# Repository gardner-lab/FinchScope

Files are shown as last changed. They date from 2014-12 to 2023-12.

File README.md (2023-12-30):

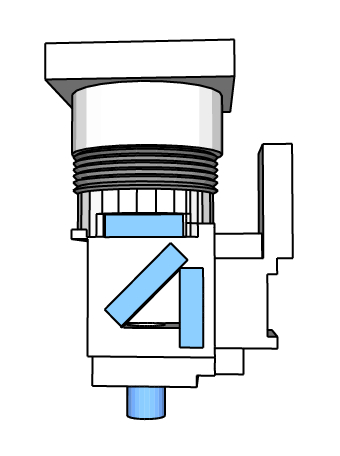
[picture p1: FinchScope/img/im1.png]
<font size="10"> FreedomScope Project</font>
=======

============

## Overview

FreedomScope is an umbrella project for several customizable and scaleable single-photon fluorescent imaging microscope systems that take advantage of developing open-source landscape to provide a modular in-vivo  all optical neurophysiology rigs with a transparent hardware, and  acquisition and analysis software.

You can read more about the project [here.](http://iopscience.iop.org/1741-2552/14/4/045001/)

The project was developed by [Will Liberti](https://github.com/WALIII) in the [Gardner Lab](http://people.bu.edu/timothyg/Home.html), for multi-month imaging of neural activity in songbirds [[1]](https://doi.org/10.1371/journal.pbio.1002158) [[2]](https://www.nature.com/articles/nn.4405) [[3]](https://ccneuro.org/2018/proceedings/1133.pdf) bats, and rodents. This effort would not have been possible without the critical advice and support at the outset of the project by Daniel Aharoni and Peyman Golshani, of the [UCLA Miniscope project](http://miniscope.org/index.php?title=Main_Page)

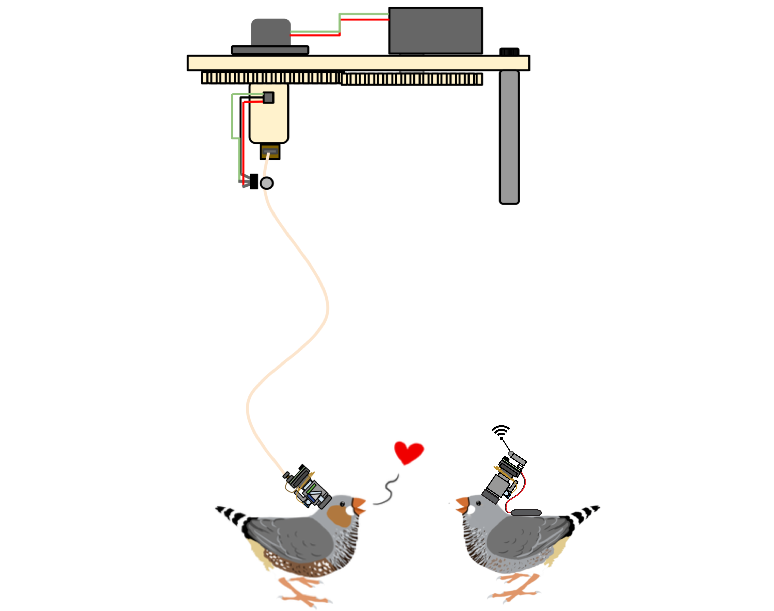
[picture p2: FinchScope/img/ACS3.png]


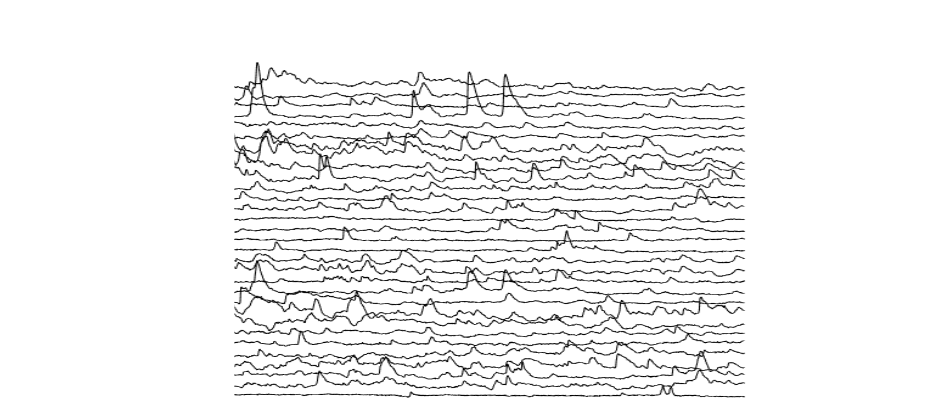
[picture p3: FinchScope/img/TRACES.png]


#### Components:

### Finchscope Microscope

The FinchScope is a lightweight wireless-capable microscope for biological imaging- Designed specifically for monitoring the neural activity (via genetically encoded calcium indicators) of zebra finches while they sing their courtship songs:

<p align="center" width="100%">
    
</p>

You can find the Construction and Assembly Guide for [the Microscope](https://github.com/WALIII/FreedomScope/wiki/Assembly-Guide), As well as a for the [Data Acquisition Box (DAQ)](https://github.com/WALIII/FreedomScope/wiki/DAQ-Guide).  Also, we have a [Guide Through a Basic Analysis Pipeline](https://github.com/WALIII/FreedomScope/wiki/Analysis-Guide)

#### Wireless Finchscope
The FinchScope is wireless capable and is being used in bats with the Yartsev lab:

<p align="center" width="100%">
    
</p>

Additional resources related to this project can be found (here.)https://github.com/WALIII/ImBat

### 1P2C Microscope (Under Development)
The 1P2C Miniscope is a variant of the FinchScope that incorporates a second excitation path for dual color imaging, or for widefield photo- stimulation.  You can find the Construction and Assembly Guide for [the Microscope](https://github.com/WALIII/FreedomScope/wiki/Assembly-Guide), As well as a for the [Data Acquisition Box (DAQ)](https://github.com/WALIII/FreedomScope/wiki/DAQ-Guide).

### Widefield Microscope (Under Development)
The WideField miniature microscope weighs 4g and gives a 4x3mm field of view. You can find the Construction and Assembly Guide for [the Microscope](https://github.com/WALIII/FreedomScope/wiki/Assembly-Guide), As well as a for the [Data Acquisition Box (DAQ)](https://github.com/WALIII/FreedomScope/wiki/DAQ-Guide).

### Active Commutator
The [Active Commutator](https://github.com/WALIII/FreedomScope/wiki/Commutators) is a low cost, low noise, active (driven by a motor and sensor) electrical rotary joint designed for electrophysiology (single and multichannel micro-electrode arrays) and optophysiology ( optogenetics, miniature microscopes, and fiber photometry).

### Referencing
If you use any part of this project in your work, please cite our Journal of Neural Engineering Paper:

[Liberti III, William A., et al. "An open source, wireless capable miniature microscope system." Journal of neural engineering 14.4 (2017): 045001.](http://iopscience.iop.org/1741-2552/14/4/045001/)

### Publications that use the FinchScope:
* Liberti, W., et al.  **Nature Neuroscience** 19.12 (2016): 1665-1671.
* Liberti, W., et al.  **Journal of Neural Engineering** 14.4 (2017): 045001.
* Yanny, K., Antipa, N., Liberti, W., et al. (2020). **Light: Science & Applications**, 9(1), 1-13.
* Cohen, Y, et al.  **Nature** 582.7813 (2020): 539-544.
* Leman, D., et al.  **(BioRxiv)** (2021).
* Singh Alvarado, J., et al. **Nature** 599.7886 (2021): 635-639.
* Liberti, W., et al.  **Nature** 604.7904 (2022): 98-103.
* Forli, A., et al. **Nature** 621.7980 (2023): 796-803.

## Contributors:
* [Will Liberti](wliberti@berkeley.edu) (U.C. Berkeley, LBNL, Morphosis Neurotech)
* [Nathan Perkins](lnp@bu.edu) (Apple)
* [Daniel Leman](dpleman@bu.edu) (Brandeis)
* [Jasmine Clevenger](jrclev@bu.edu) (Bosotn U.)
* [Will Yen](yenw24@gmail.com) (Boston U.)

##  Major Contributing Labs
* [Gardner Lab](idavison@bu.edu)
* [Otchy Lab](idavison@bu.edu)
* [Davison Lab](idavison@bu.edu)  
* [Cruz-Martin Lab](idavison@bu.edu)  
* [Carmena Lab](idavison@bu.edu)  
* [Yartsev Lab](idavison@bu.edu)

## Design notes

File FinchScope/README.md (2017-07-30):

<font size="10">    FinchScope</font>
============
## Overview

The project is now in live. If you have questions or find bugs, feel free to [post an issue](https://github.com/WALIII/FinchScope/issues) and I'll get on it.

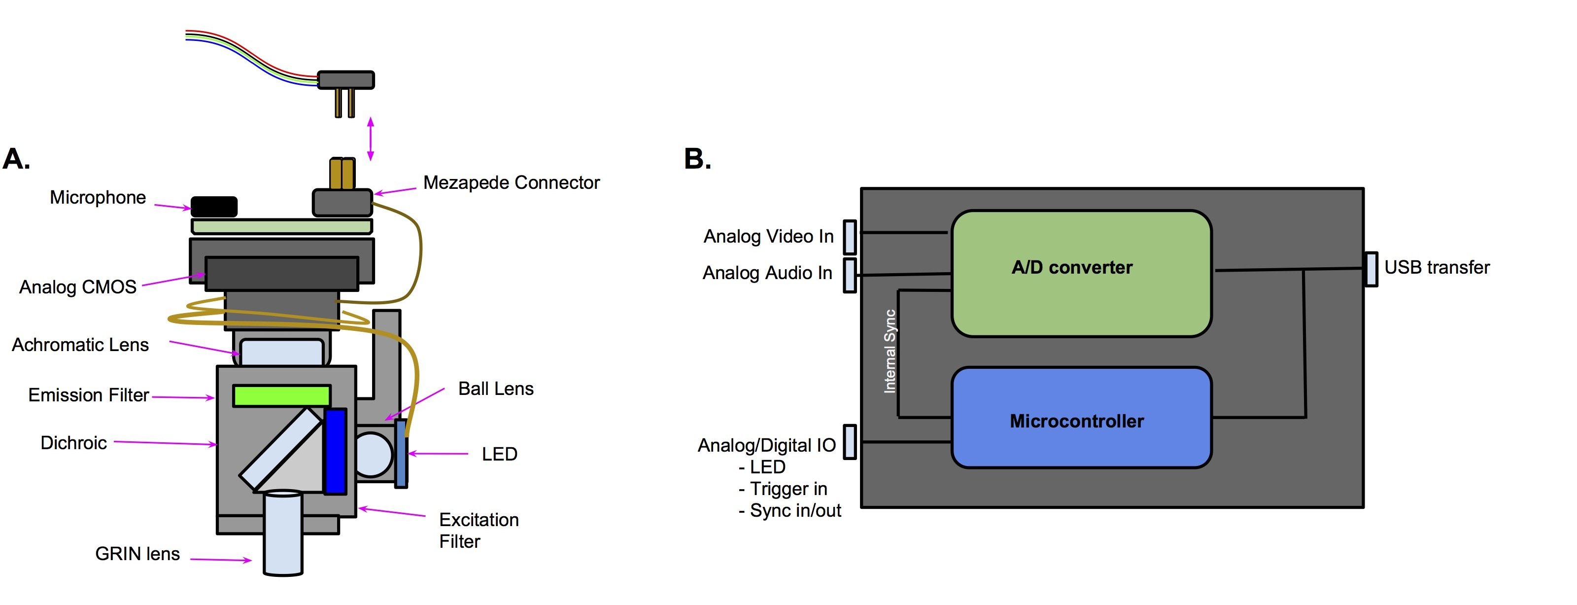
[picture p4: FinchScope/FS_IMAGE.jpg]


The FreedomScope is a lightweight (<2g) 3D printed microscope for biological imaging, specifically designed for fluorescence calcium imaging in Zebra Finches and other small animals.

#### Hardware Components:

[PARTS LIST](https://docs.google.com/a/bu.edu/spreadsheets/d/1X6249HvX6Zhh-KnQvc4uEf_1f7gnXYBuc04Sh4Ooo6Y/edit?usp=sharing)

##### Detailed Assembly Schematics:

[CAMERA](https://docs.google.com/drawings/d/1Mr2SnDT4y19bNpteDOJaQ2hIX_aQwCAYKedkWsTO91U/edit)

[TEST CABLES](https://docs.google.com/drawings/d/1CfU9u8T49LHIxU1WA31IjVRijmX2HUkyHNBYetaNZlw/edit)

[COMMUTATOR INTERFACE](https://docs.google.com/drawings/d/1axYK-PdhWuuLdrFH5zi7WUmzpqFvBdvdiIFzCNW9POA/edit)

### DAQ BOX
The DAQ converts/syncs audioIN and video, Triggers in/out, and also controls LED power levels

[DAQ Overview] (https://docs.google.com/drawings/d/1Maer1AkDQlLleWU_moi8kYX32AhPPOLMHTUVHxjg2Lc/edit)

[Internal Wiring Diagram](https://docs.google.com/drawings/d/1Maer1AkDQlLleWU_moi8kYX32AhPPOLMHTUVHxjg2Lc/edit)

I like to use [these Connectors](http://www.advanced.com/products/board-to-board-connectors/mezza-pede-smt-connectors/table-of-models)

## SOFTWARE

#####NEW Software (MAC 10.7 or later):
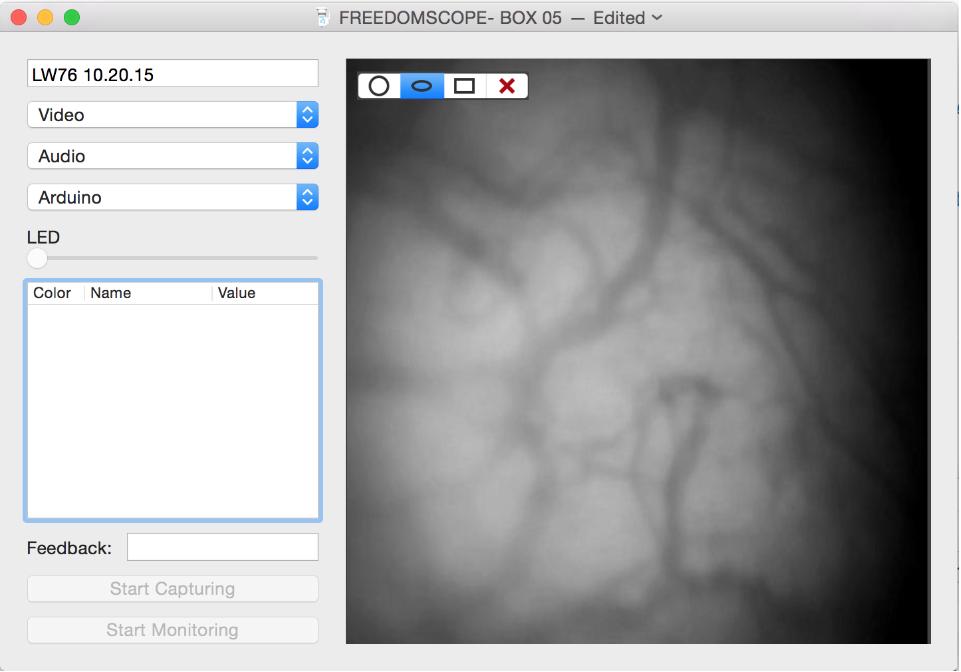
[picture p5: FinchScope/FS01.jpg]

Figure: Brightfield imagiing

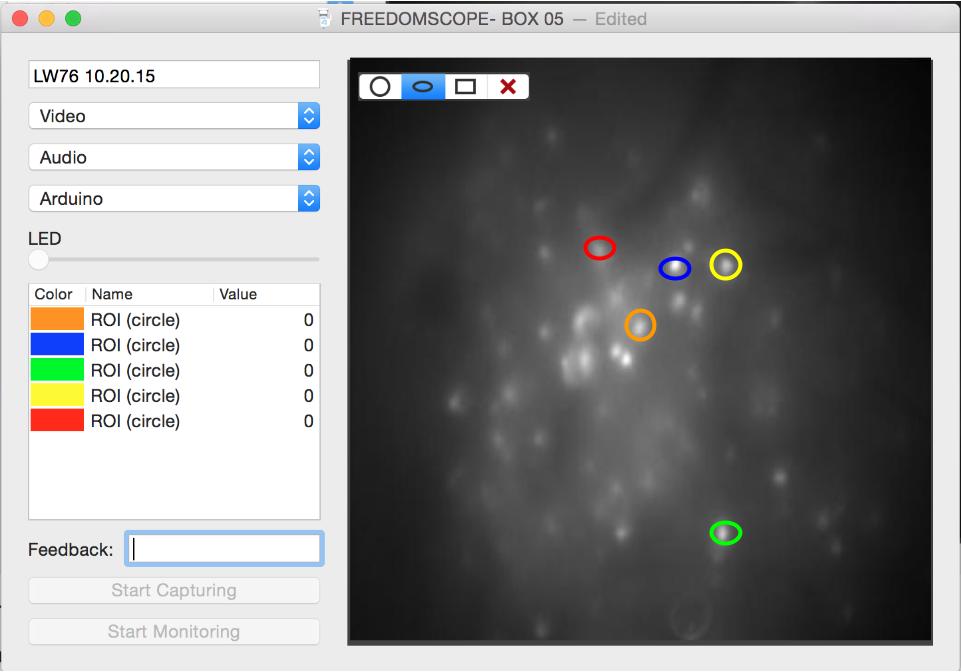
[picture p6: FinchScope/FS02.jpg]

Figure: Single channel fluorescence imaging, at cellular resolution. Low-Latency ROI information for BMI experiments.

Current software [can be found here](https://github.com/gardner-lab/video-capture/releases)

## Contact:
email bliberti@bu.edu; dpleman@bu.edu

Inspiration: http://www.nature.com/nmeth/journal/v8/n10/full/nmeth.1694.html

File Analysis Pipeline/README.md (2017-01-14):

# Basic Analysis Pipeline

A basic analysis pipeline [can be found here](https://github.com/WALIII/FinchScope/wiki/Analysis-Guide)

This code serves as a basic analysis pipeline for extracting fluorescence time series traces from the .mov files generated from the FreedomScopes. While this is a basic workflow, the exported .mov files can be used with any analysis software.

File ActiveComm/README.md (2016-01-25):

# ActiveComm

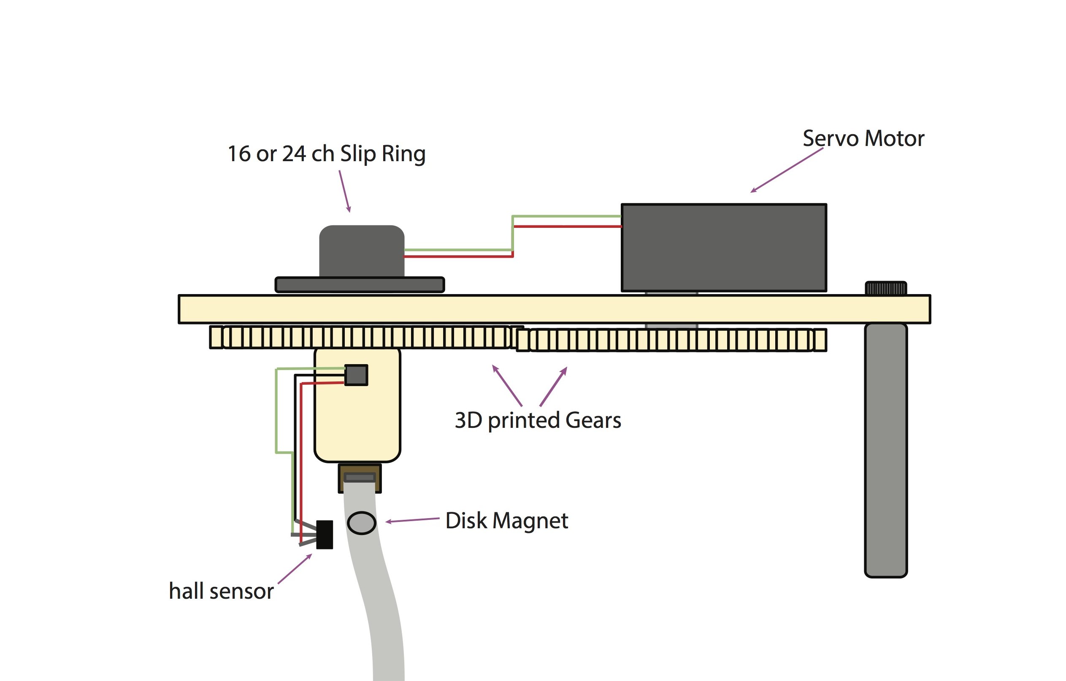
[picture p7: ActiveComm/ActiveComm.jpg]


The ActiveComm is a simple low noise active(driven by a motor and sensor) commutator designed for ABA electrophysiology and optophysiology.

Parts List:
https://docs.google.com/a/bu.edu/spreadsheets/d/18mCksBi6qS9Ah4pYq2-t6xsRfTHRStpMuj2Iyy4ihCQ/edit?usp=sharing

## Assembly

 Get 3D printed files, these can be ordered through 3D hubs, local hackerspace/makespace, or local university service.

 Boston University has mid/low-resolution 3D printing  on site-

Schematic:
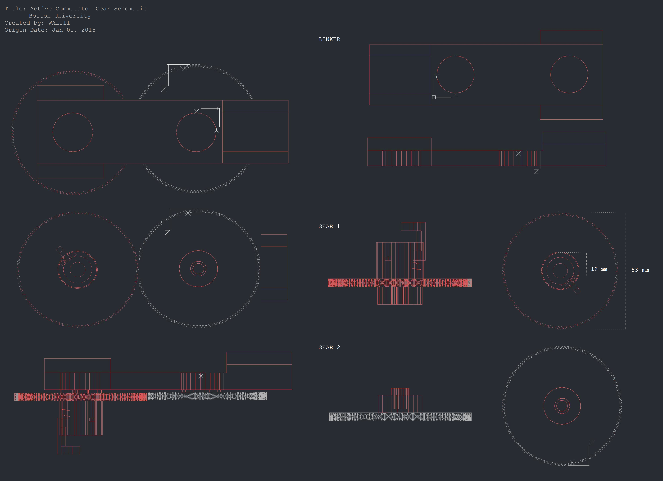
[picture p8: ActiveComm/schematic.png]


### Wiring Diagram:
The wiring is simple. Here is a simple wiring diagram of the circuit:

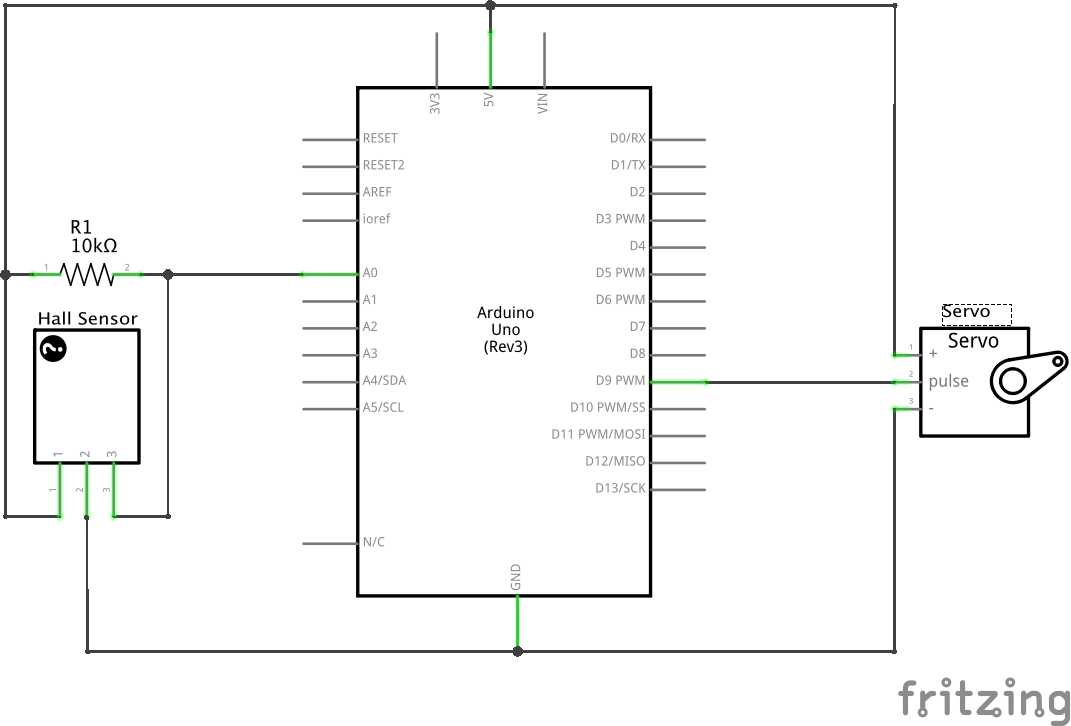
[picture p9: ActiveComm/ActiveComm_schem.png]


On the Arduino:

    PIN 09: Servo output
    PIN A0: Hall sensor output

Make sure the Hall sensor is wired correctly:

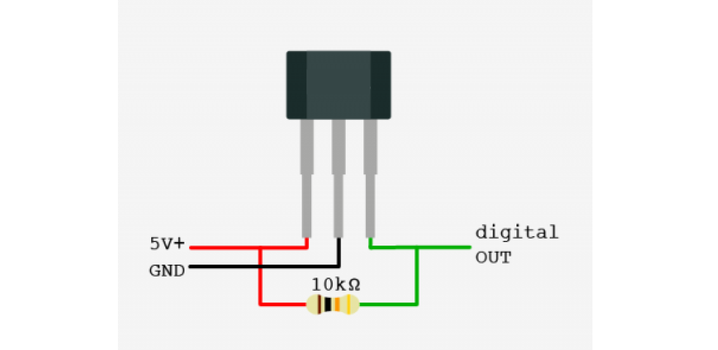
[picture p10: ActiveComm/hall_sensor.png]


On the serial monitor, with no magnet, pin A0 should read ~512. Bringing a magnet close to the sensor will cause this value to increase or decrease, depending on the deflection. The sketch is programmed to do this already.

On the cable, the Magnet should sit just below the hall sensor (see IMAGES dir)

## Inspiration:
This was inspired by work done in Michale Fee's lab, by Anthony Leonardo.  

http://web.mit.edu/fee/Public/Publications/FeeLeonardo2001.pdf

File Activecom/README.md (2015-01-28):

###ActiveComm
The ActiveComm is a simple low noise active(driven by a motor and sensor) commutator designed for ABA electrophysiology and optophysiology.

Parts List:
https://docs.google.com/a/bu.edu/spreadsheets/d/18mCksBi6qS9Ah4pYq2-t6xsRfTHRStpMuj2Iyy4ihCQ/edit?usp=sharing

Schematics

(1): https://docs.google.com/a/bu.edu/drawings/d/1YxSafQaIYxEDBTFbJCvKYJh-I-m52XN8J2makgpTJ8w/edit?usp=sharing

(2):

Inspiration:
http://web.mit.edu/fee/Public/Publications/FeeLeonardo2001.pdf

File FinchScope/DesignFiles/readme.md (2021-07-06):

## Extrenal Design files

Enclosure files for bats and rats can be found [here.](https://github.com/WALIII/ImBat/tree/master/3d_files/Miniscope_Enclosure)

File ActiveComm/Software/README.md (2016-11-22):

## Active Commutator

ActiveCommMk1: For active commutators driven by servo motors. reads from sensor every */200ms

ActiveCommMk2: This is identical to ActiveCommMk1, but has magnet orientation swapped, and reads from sensor  */50ms.

CommutatorMk3: For quieter, stepper motor driven commutators. Requires some additional hardware (i.e. stepper motor and stepper motor driver). Additional parts may not interface smoothly with servo driven design.

## Loading the software:

As a troubleshooting measure, the code incorporates a readout of the Hall sensor value. 10 bit ADC gives the range from 0-1024. A lack of magnetic field should read a value of  ~512. A positive/negative magnetic deflection should give a reading above or below this reading. The code is calibrated for the sensor listed in the parts file.

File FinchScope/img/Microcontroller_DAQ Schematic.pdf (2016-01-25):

## Microcontroller/DAQ Schematic

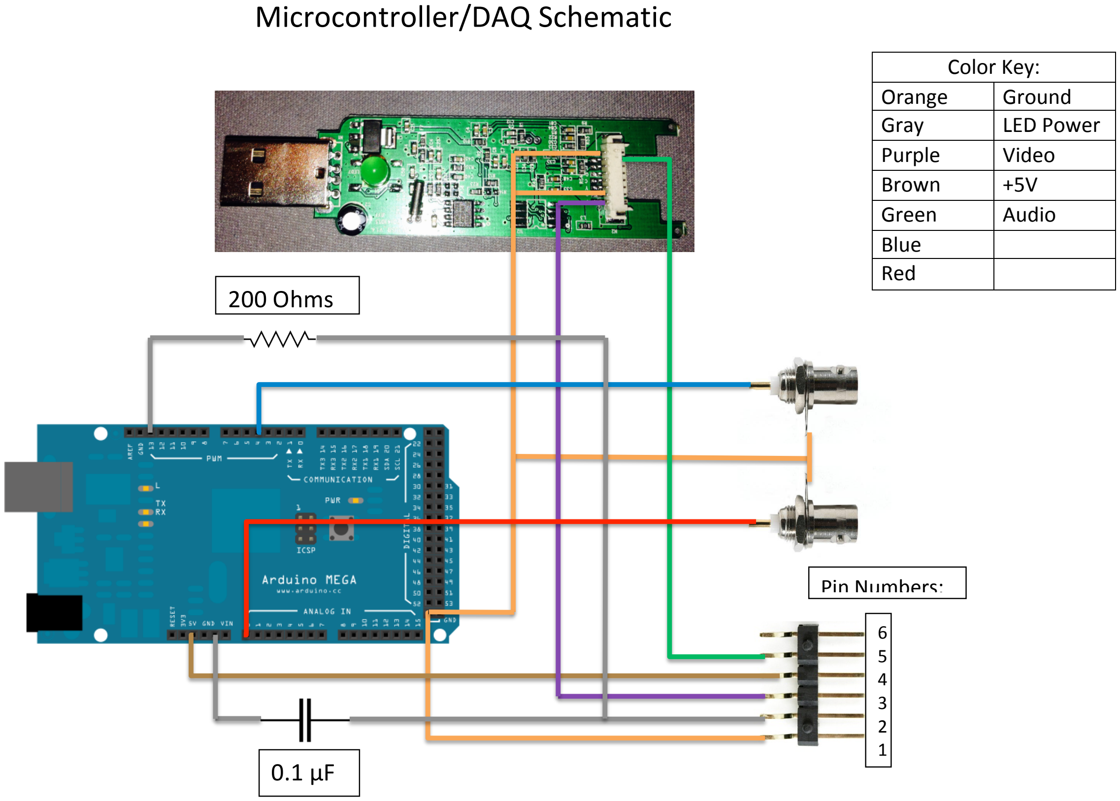
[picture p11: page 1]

Color Key:
Orange | Ground
Gray | LED Power
Purple | Video
Brown | +5V
Green | Audio
Blue
Red
200 Ohms

0.1 µF

6
5
4
3
2
1

Pin Numbers:

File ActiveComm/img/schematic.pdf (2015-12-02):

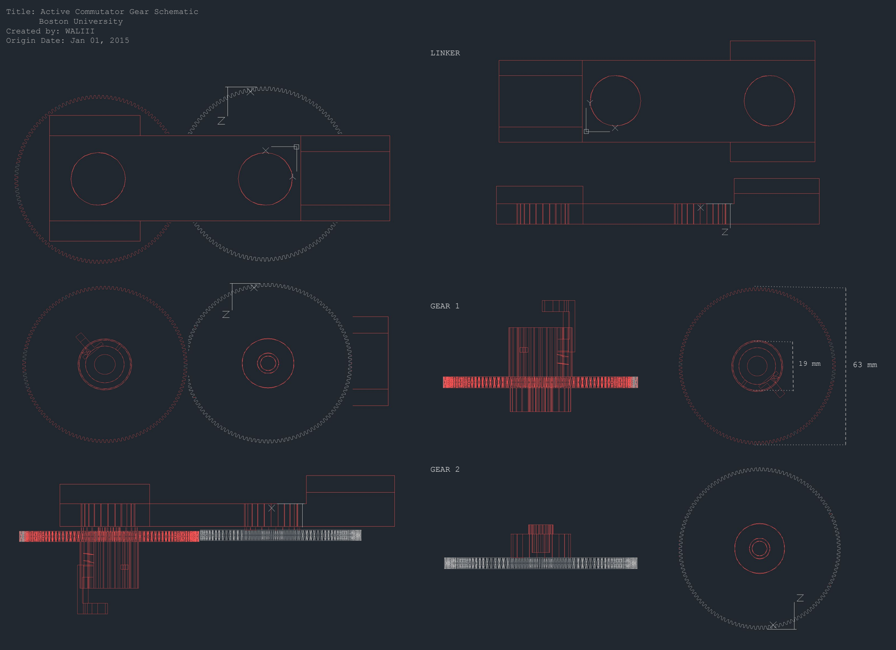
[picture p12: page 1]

19 mm | 63 mm

Title: Active Commutator Gear Schematic Boston University
Created by: WALIII
Origin Date: Jan 01, 2015

LINKER

GEAR 1

GEAR 2

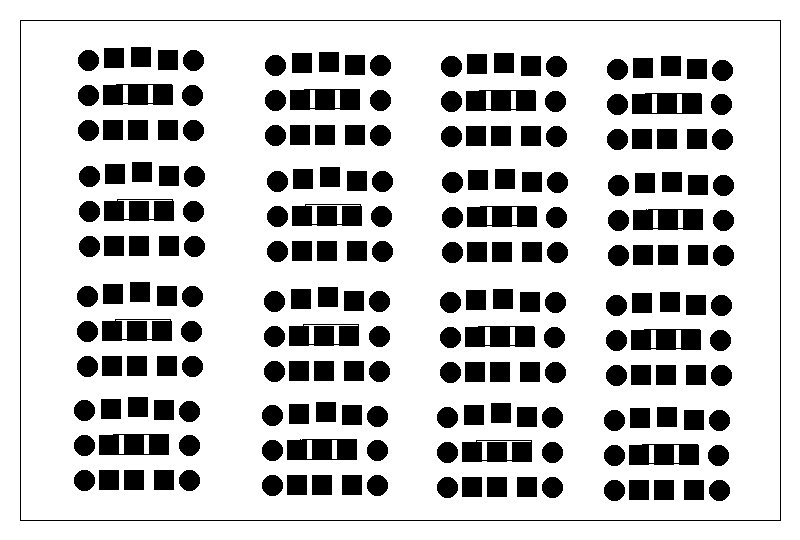
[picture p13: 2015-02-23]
Activecom/DesignFiles/ActiveCommutator/commutator_adapter_fullsheet.bmp

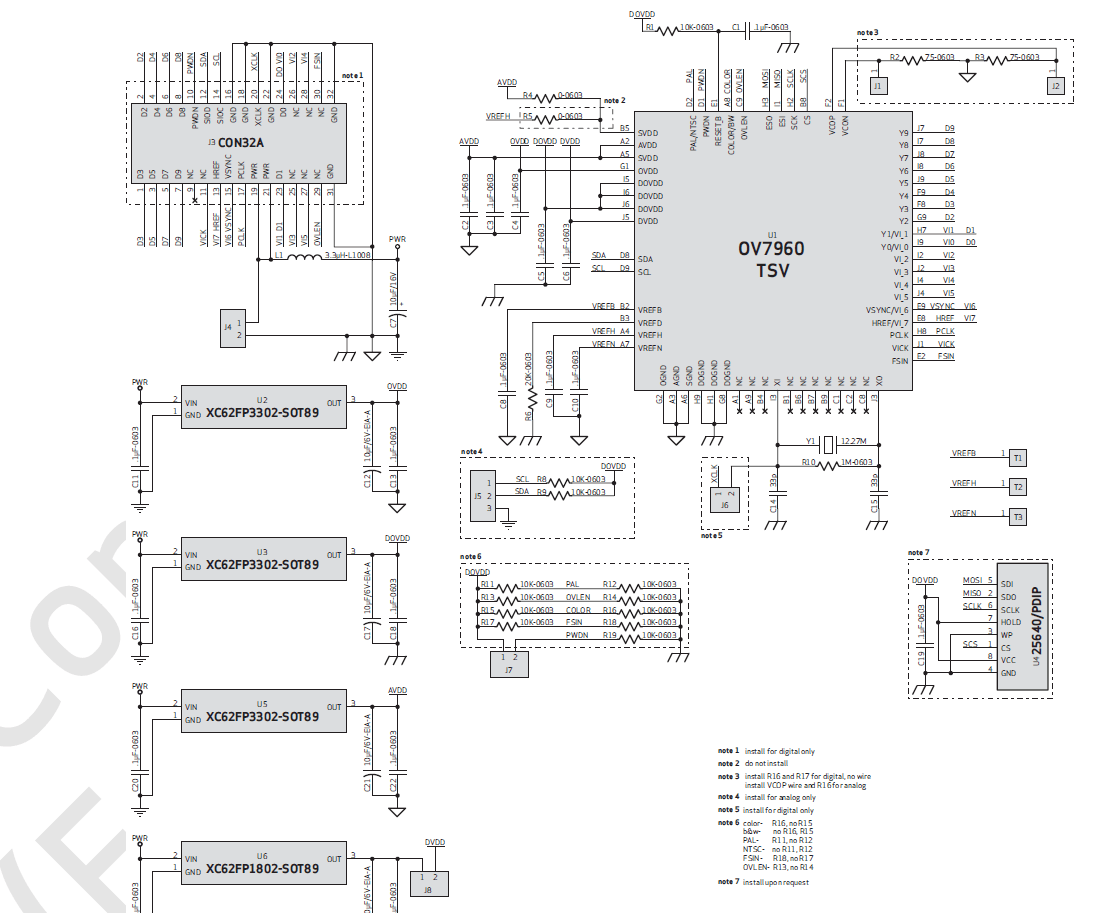
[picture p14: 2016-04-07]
FinchScope/img/mc900 电路图.png

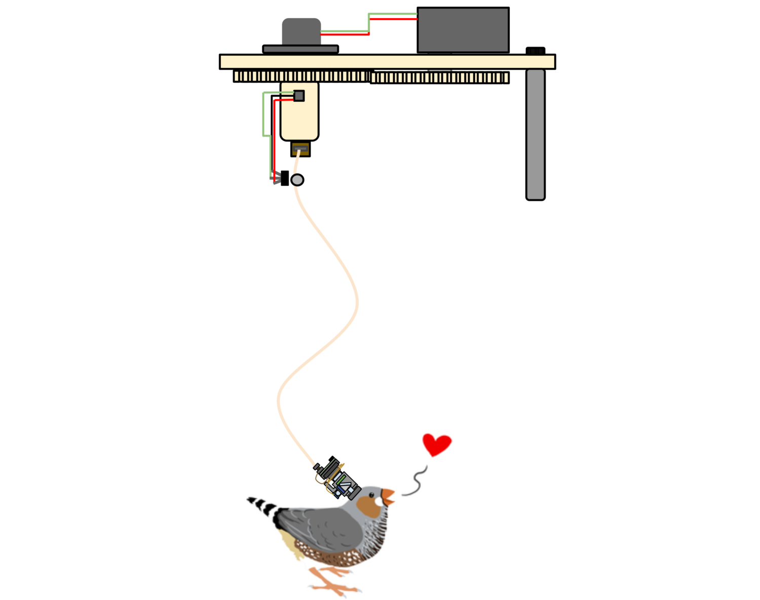
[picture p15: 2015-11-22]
FinchScope/img/ACS3_1.png

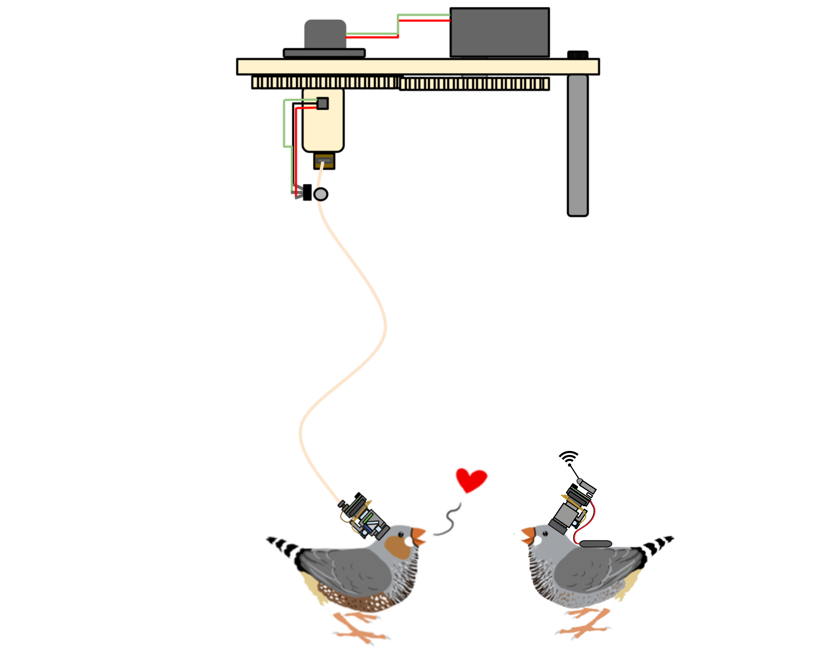
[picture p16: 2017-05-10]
FinchScope/img/ACS3_2.png

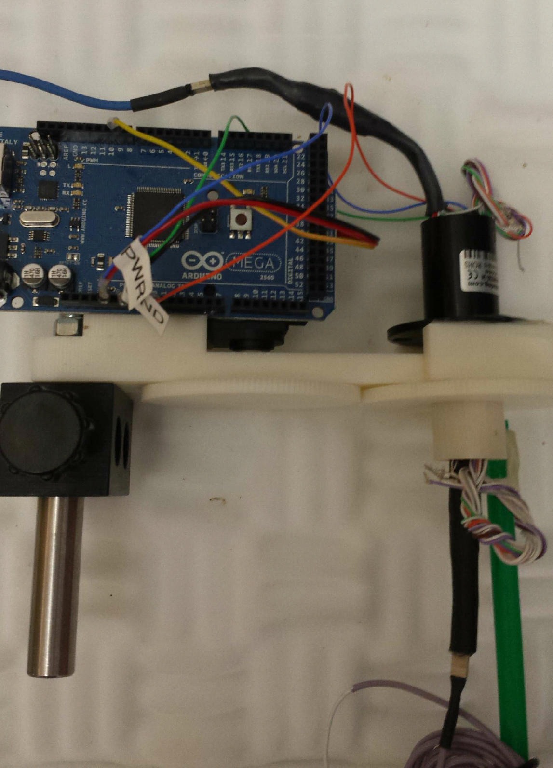
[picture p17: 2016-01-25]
ActiveComm/img/Commutator_Cables.png

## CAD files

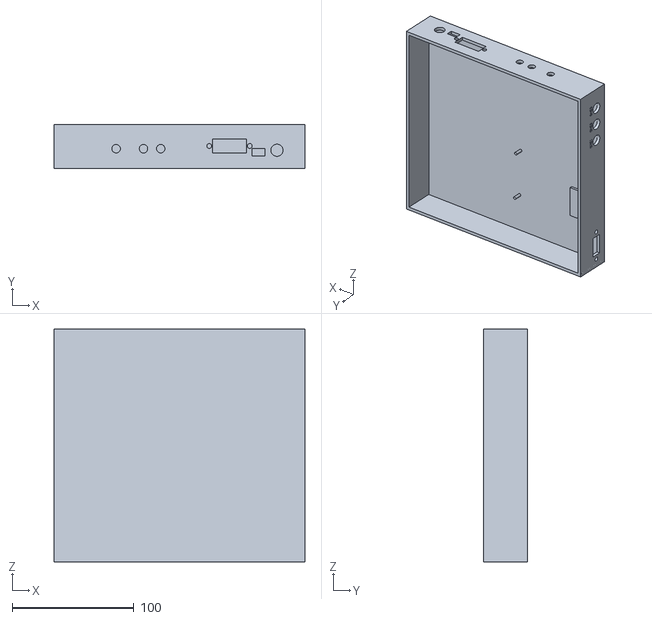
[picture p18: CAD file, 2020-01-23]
Commutator Box Full.STL
206.0 x 36.4 x 191.1

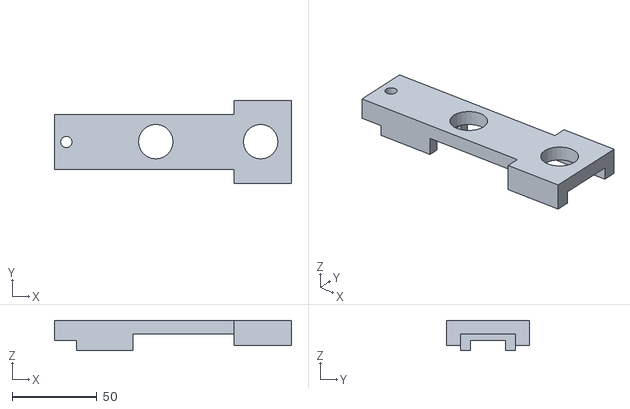
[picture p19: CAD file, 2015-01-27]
Activecom/DesignFiles/ActiveCommutator/ActiveCommLinkerMk1.1.stl
140.1 x 48.8 x 18.0

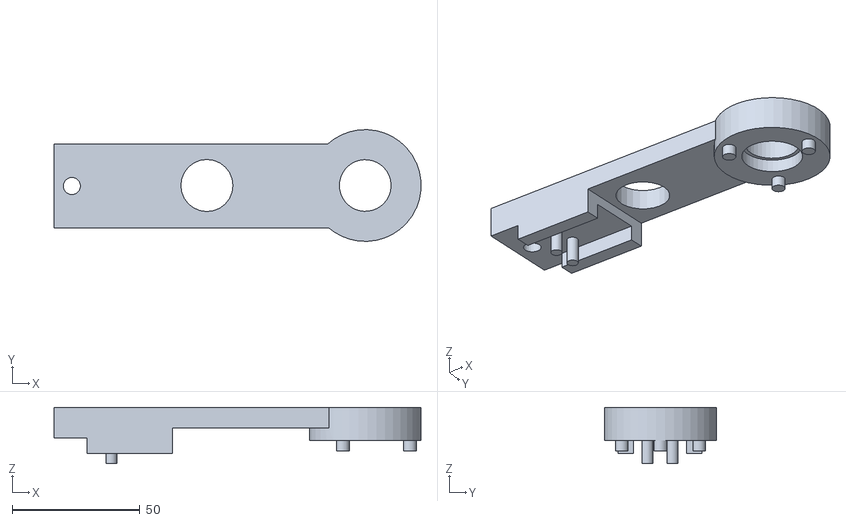
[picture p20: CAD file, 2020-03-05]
ActiveComm/DesignFiles/ActiveCommutator/Active_Commutaor_Linker.STL
143.7 x 43.8 x 22.0

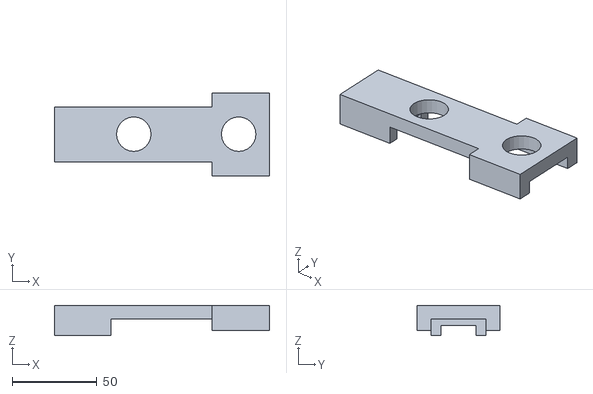
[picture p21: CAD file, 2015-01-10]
DesignFiles/ActiveCommutator/ActiveCommLinker.stl
127.1 x 48.8 x 18.0

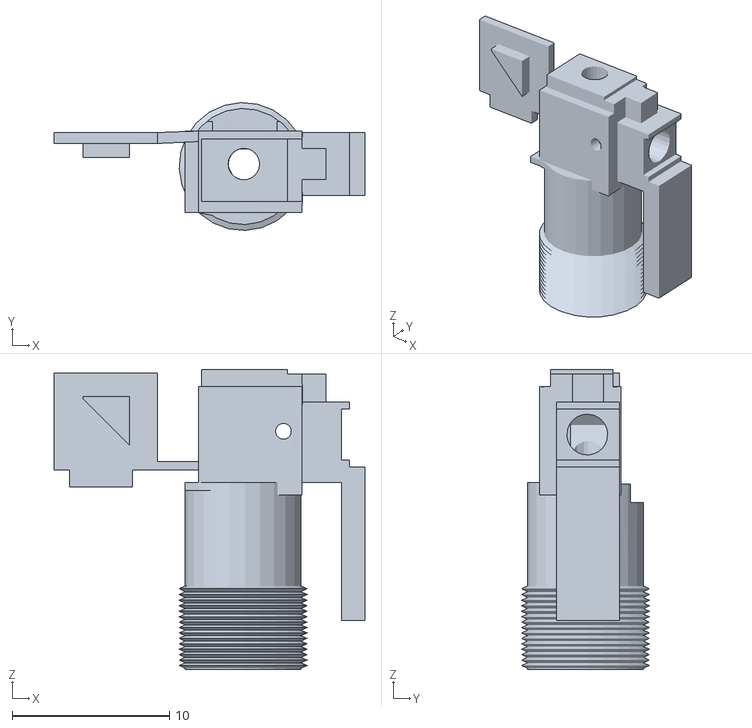
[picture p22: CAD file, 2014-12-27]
DesignFiles/FinchScopeMk4.7.stl
19.8 x 8.14 x 19.1

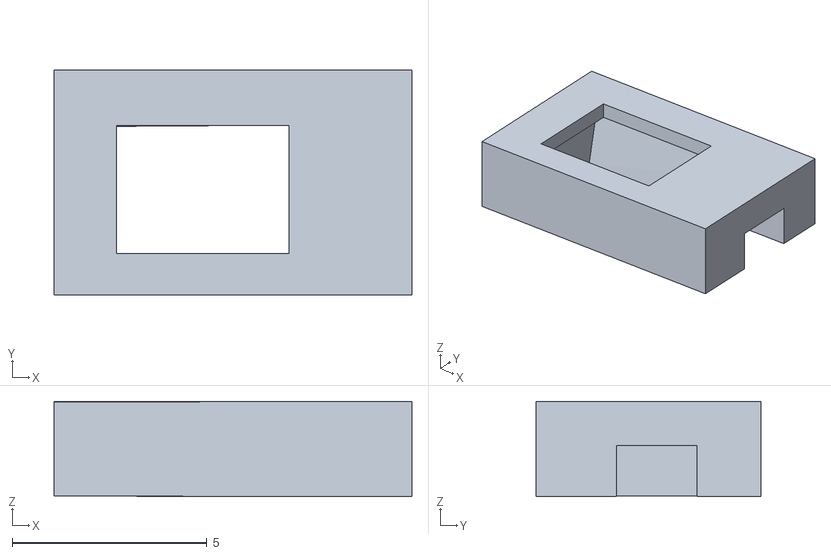
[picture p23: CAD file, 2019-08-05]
FinchScope/DesignFiles/CaBMI_miniscope/CaBMI_BasePlate_which.stl
9.19 x 5.77 x 2.44

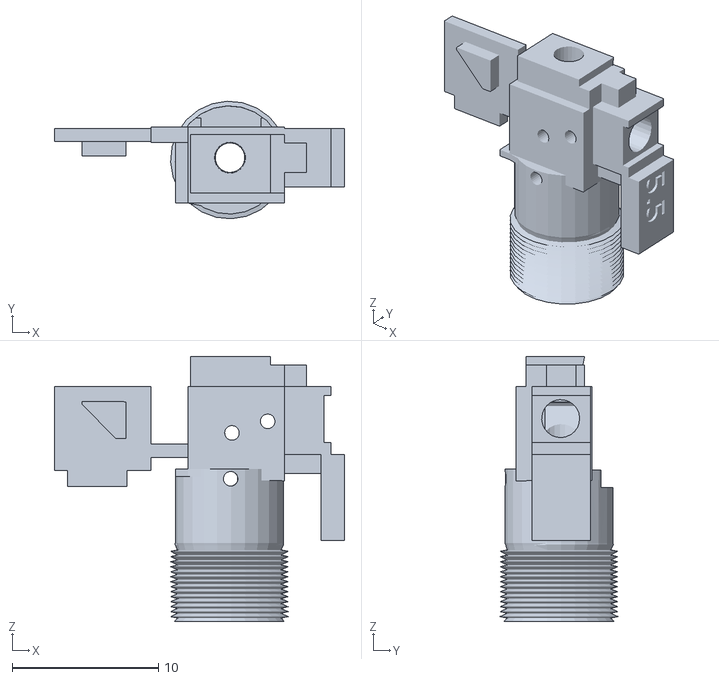
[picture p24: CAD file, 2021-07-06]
FinchScope/DesignFiles/CaBMI_miniscope/CaBMI_long_stem/CaBMI_miniscope_long_stem.stl
19.8 x 8.03 x 18.1

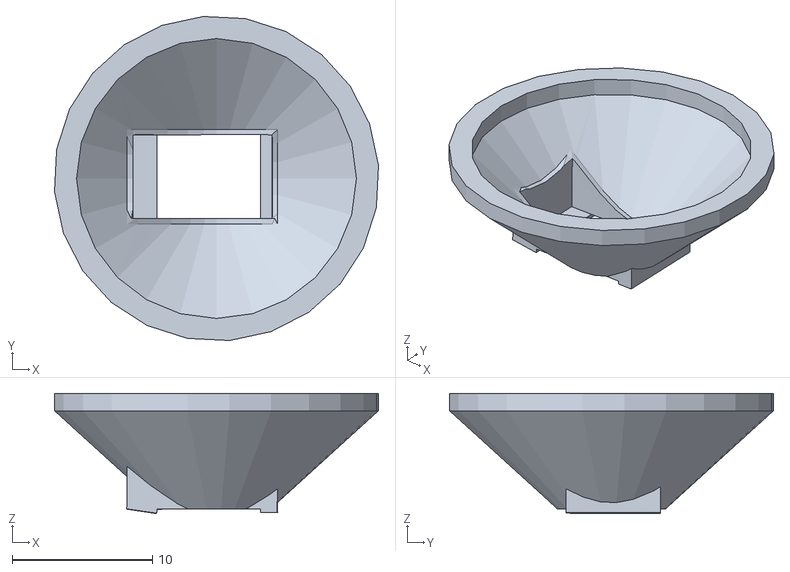
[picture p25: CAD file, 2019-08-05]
FinchScope/DesignFiles/CaBMI_miniscope/Miniscope_2P_converter/XXXminiTo2P.stl
23.1 x 23.1 x 8.58

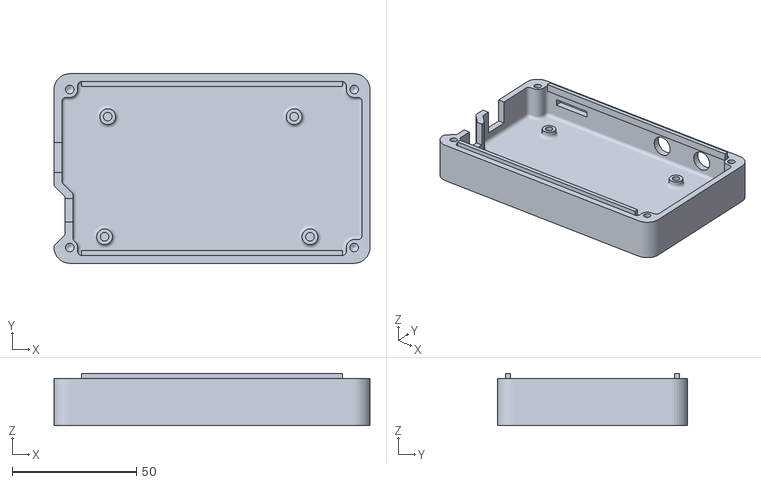
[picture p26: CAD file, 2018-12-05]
FinchScope/DesignFiles/Enclosure/Bottem.stl
127.0 x 76.2 x 21.0

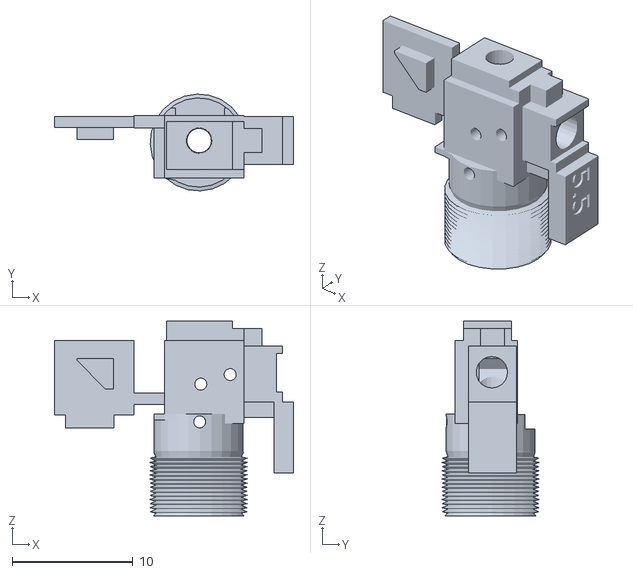
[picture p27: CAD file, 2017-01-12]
FinchScope/DesignFiles/FinchScope/Microscope Housing (FS_122016_2.0mm).stl
19.8 x 8.03 x 16.2

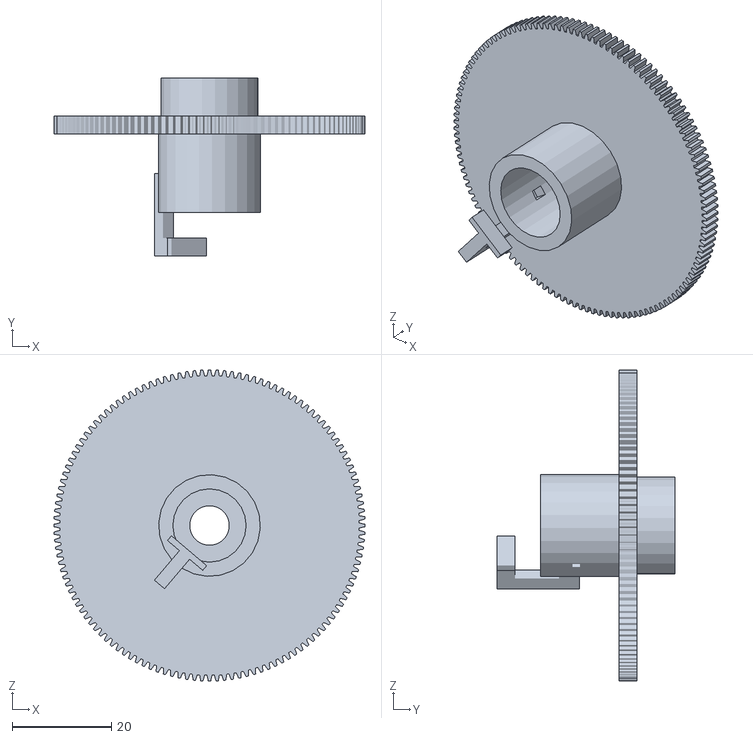
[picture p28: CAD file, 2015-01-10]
Activecom/DesignFiles/ActiveCommutator/ActiveCommGear1.stl
62.8 x 35.9 x 62.8

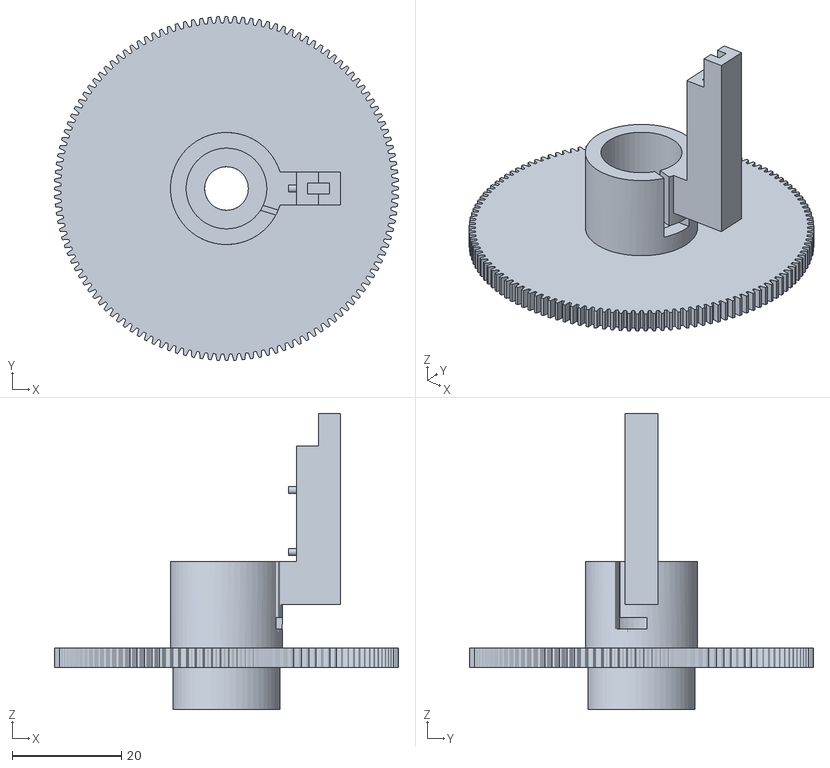
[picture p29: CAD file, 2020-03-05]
ActiveComm/DesignFiles/ActiveCommutator/Active_Commutator_Gear_1.STL
63.0 x 63.0 x 54.2

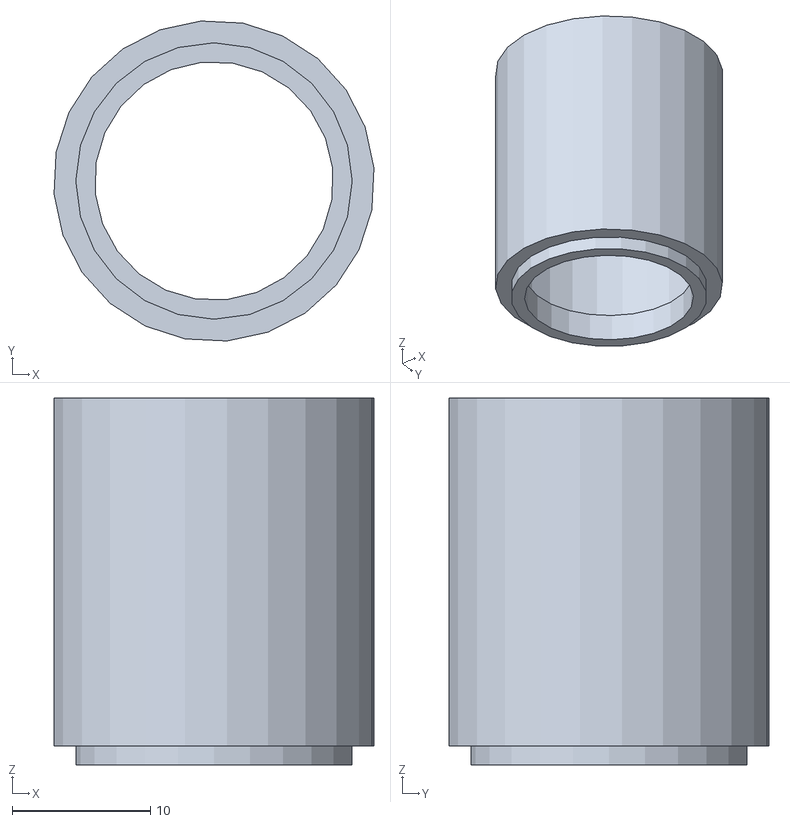
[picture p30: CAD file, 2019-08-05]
FinchScope/DesignFiles/CaBMI_miniscope/Head_cone_miniscope_mk_testing.stl
23.1 x 23.1 x 26.5

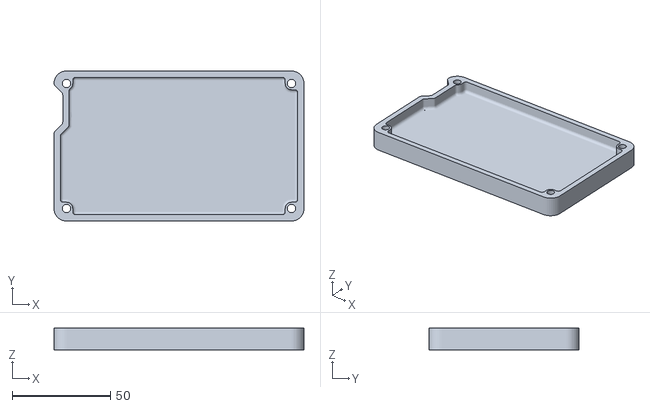
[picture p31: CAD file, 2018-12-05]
FinchScope/DesignFiles/Enclosure/top.stl
127.0 x 76.2 x 11.1

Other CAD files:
DesignFiles/FinchScopeMk4.6.stl
FinchScope/DesignFiles/FinchScope/BaseplateMk1.3.stl
Activecom/DesignFiles/ActiveCommutator/ActiveCommGear2.stl
ActiveComm/DesignFiles/ActiveCommutator/ActiveCommGear1.skp
ActiveComm/DesignFiles/ActiveCommutator/ActiveCommGear2.skp
ActiveComm/DesignFiles/ActiveCommutator/ActiveCommGear2.stl
ActiveComm/DesignFiles/ActiveCommutator/ActiveCommLinker.skp
ActiveComm/DesignFiles/ActiveCommutator/Objective_Cap.skp
FinchScope/DesignFiles/CaBMI_miniscope/CaBMI_BasePlate.skp
FinchScope/DesignFiles/CaBMI_miniscope/CaBMI_BasePlate.stl
FinchScope/DesignFiles/CaBMI_miniscope/CaBMI_BasePlate_adjust_190523.stl
FinchScope/DesignFiles/CaBMI_miniscope/CaBMI_BasePlate_adjust_190523~.skp
FinchScope/DesignFiles/CaBMI_miniscope/CaBMI_BasePlate_v2.stl
FinchScope/DesignFiles/CaBMI_miniscope/CaBMI_long_stem/CaBMI_miniscope_long_stem.skp
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

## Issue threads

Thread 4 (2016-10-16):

Add potentiometer option for wireless schematic

WALIII, 2016-10-16:
Add LED control through a potentiometer, instead of a IR sensor- add documentation for this

WALIII, 2017-01-11:
done

Closed 2017-01-11.

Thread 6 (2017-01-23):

FS_TemplateMatch selection issue

WALIII, 2017-01-23:
issue with matlab 2016b ( but not previous versions) when using FS_TemplateMatch

-Red/blue selection identifiers are obscured in clustering GUI
-Re-sizing window window changes selection on GUI.

WALIII, 2018-12-05:
fixed in current MATLAB versions

Closed 2018-12-05.

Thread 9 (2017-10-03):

Active Comm Hall Effect Sensor

guitchounts, 2017-10-03:
Schematic in Readme shows hall effect sensor US1881. This is the wrong sensor (it's a latching one). Change schematic label to show "A1301EUA-T" sensor?

WALIII, 2017-10-03:
Fixed.

Closed 2017-10-03.

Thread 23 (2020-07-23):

Add Finchscope to Open Neuroscience

amchagas, 2020-07-23:
Hello!

We are reaching out because we would love to have your project listed on [Open Neuroscience](<https://open-neuroscience.com>), and also share information about this project:

Open Neuroscience is a community run project, where we are curating and highlighting open source projects related to neurosciences!

Briefly, we have a website where short descritptions about projects are listed, with links to the projects themselves, their authors, together with images and other links.

Once a new entry is made, we make a quick check for spam, and publish it.

Once published, we make people aware of the new entry by [Twitter](https://twitter.com/openneurosci) and a [Facebook](https://www.facebook.com/OpenNeuroscience) group.

**To add information about their project, developers only need to fill out this [form](https://forms.gle/ByM8thAhZJkHBMQN8)**

In the form, people can add subfields and tags to their entries, so that projects are filterable and searchable on the website!

The reason why we have the form system is that it makes it open for everyone to contribute to the website and allows developers themselves to describe their projects!

Also, there are so many amazing projects coming out in Neurosciences that it would be impossible for us to keep track and log them all!

Please [get in touch](mailto:openeuroscience@gmail.com) if you have any questions or would like to collaborate!

WALIII, 2020-07-29:
Sounds like fun- I'll fill out the form!

Closed 2020-07-29.

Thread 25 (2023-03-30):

Consulting MB001 related issues

931436690, 2023-03-30:
Hi,there.
 We want to build a similar wireless imaging system (using the MB001 analog camera mentioned in your paper); we bought the MB001 camera from a company in China, but the camera has 'Auto Gain Control' function; 'Automatic Gain Control' function affects the image display (the image is overexposed; in the image, we can only see a large circle of white area, and the animal's cerebral cortex cannot be seen clearly). The pictures below are the camera imaging image (the central area of the image is very bright), and the picture of MB001’s parameters.
![U
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
ploading 1111.png…]()

Have you encountered a similar problem, any suggestions for this?
Look forward to hearing from you soon.
Best Wishes.

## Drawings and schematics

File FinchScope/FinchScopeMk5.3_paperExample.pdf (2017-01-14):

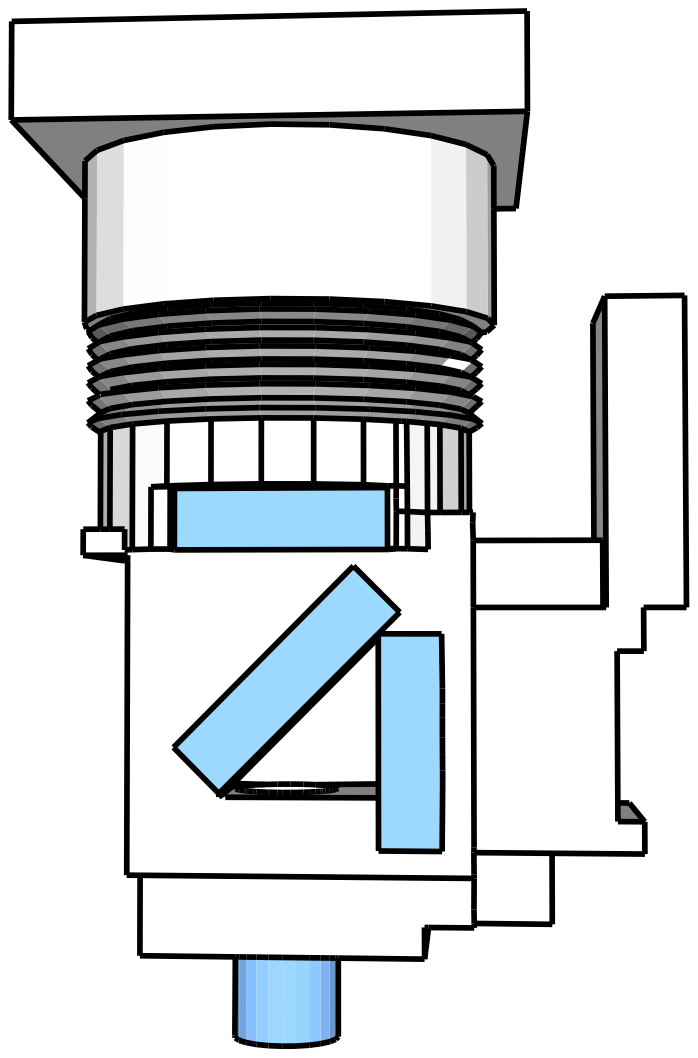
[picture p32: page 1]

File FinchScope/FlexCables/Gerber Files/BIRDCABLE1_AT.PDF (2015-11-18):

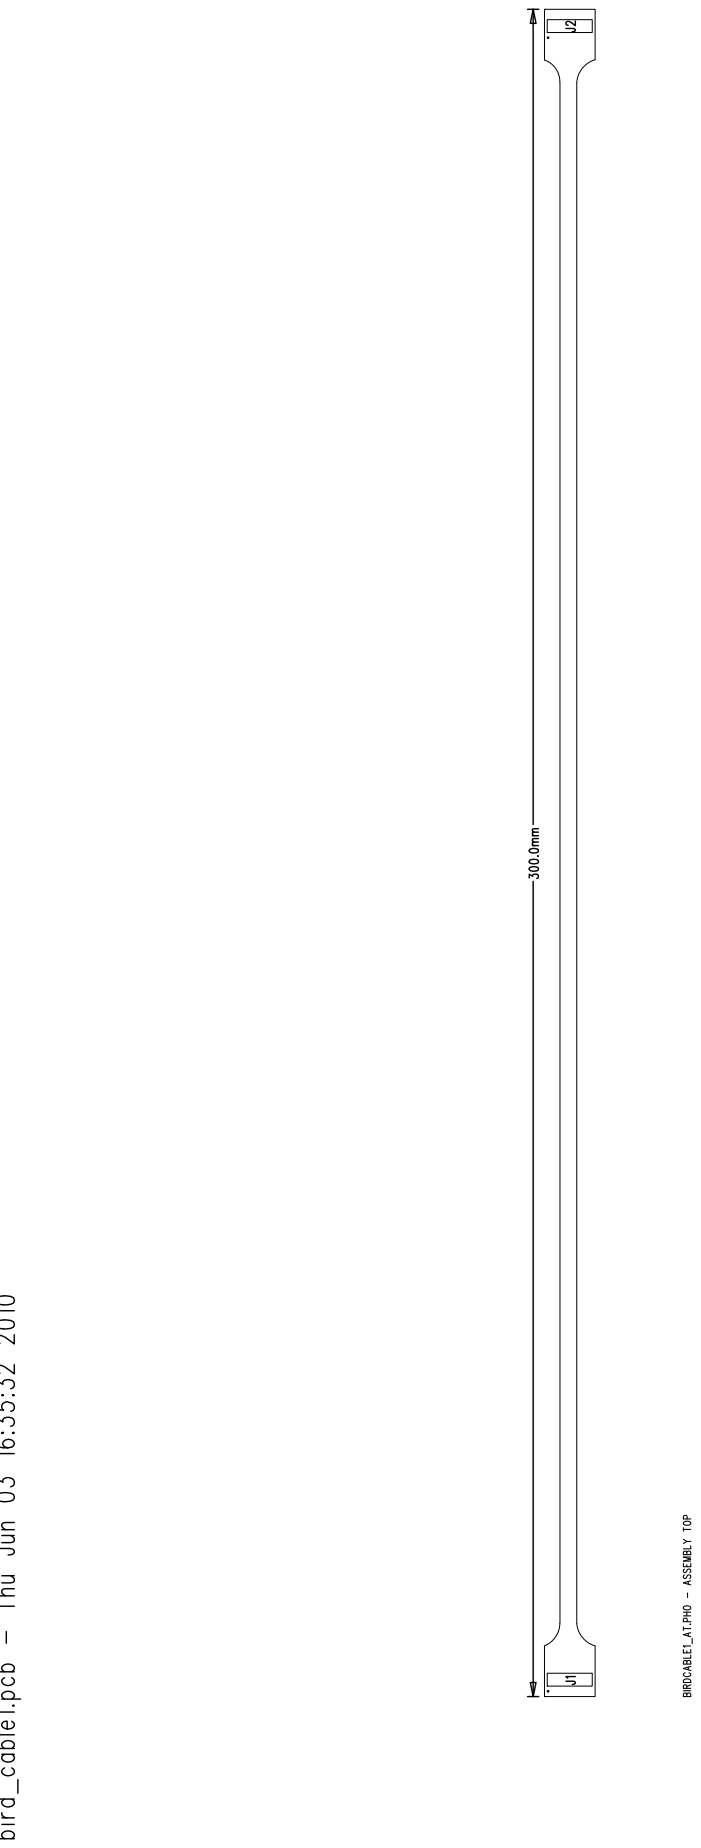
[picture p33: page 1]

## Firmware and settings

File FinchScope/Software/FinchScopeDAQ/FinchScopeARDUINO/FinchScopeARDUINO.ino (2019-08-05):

//--------------------------------------------------------------------//
//          FINCHSCOPE ARDUINO MK 1.0
//--------------------------------------------------------------------//

/* MODIFIED by WALIII, based on cobe by Analog and Digital Input and 
Output Server for MATLA Giampiero Campa, Copyright 2013 The MathWorks, Inc */




/* This file is meant to be used with the MATLAB arduino IO 
   package, however, it can be used from the IDE environment
   (or any other serial terminal) by typing commands like:
   
   0e0 : assigns digital pin #4 (e) as input
   0f1 : assigns digital pin #5 (f) as output
   0n1 : assigns digital pin #13 (n) as output   
   
   1c  : reads digital pin #2 (c) 
   1e  : reads digital pin #4 (e) 
   2n0 : sets digital pin #13 (n) low
   2n1 : sets digital pin #13 (n) high
   2f1 : sets digital pin #5 (f) high
   2f0 : sets digital pin #5 (f) low
   4j2 : sets digital pin #9 (j) to  50=ascii(2) over 255
   4jz : sets digital pin #9 (j) to 122=ascii(z) over 255
   3a  : reads analog pin #0 (a) 
   3f  : reads analog pin #5 (f) 

   R0    : sets analog reference to DEFAULT
   R1    : sets analog reference to INTERNAL
   R2    : sets analog reference to EXTERNAL
  
   X3    : roundtrip example case returning the input (ascii(3)) 
   99    : returns script type (0 adio.pde ... 3 motor.pde ) */
   
/* define internal for the MEGA as 1.1V (as as for the 328)  */
#if defined(__AVR_ATmega1280__) || defined(__AVR_ATmega2560__)
#define INTERNAL INTERNAL1V1
#endif

void setup() {
  // set PIN13 to PWM to 62khz
  int myEraser = 7;             // this is 111 in binary and is used as an eraser
  TCCR0B &= ~myEraser;   // this operation (AND plus NOT),  set the three bits in TCCR2B to 0
  int myPrescaler = 1;         // this could be a number in [1 , 6]. In this case, 3 corresponds in binary to 011.   
  TCCR0B |= myPrescaler;  //this operation (OR), replaces the last three bits in TCCR2B with our new value 011 
  /* initialize serial                                       */
  Serial.begin(115200);
  
}


void loop() {
  
  /* variables declaration and initialization                */
  
  static int  s   = -1;    /* state                          */
  static int  pin = 13;    /* generic pin number             */
 
  int  val =  0;           /* generic value read from serial */
  int  agv =  0;           /* generic analog value           */
  int  dgv =  0;           /* generic digital value          */


  /* The following instruction constantly checks if anything 
     is available on the serial port. Nothing gets executed in
     the loop if nothing is available to be read, but as soon 
     as anything becomes available, then the part coded after 
     the if statement (that is the real stuff) gets executed */

  if (Serial.available() >0) {

    /* whatever is available from the serial is read here    */
    val = Serial.read();
    
    /* This part basically implements a state machine that 
       reads the serial port and makes just one transition 
       to a new state, depending on both the previous state 
       and the command that is read from the serial port. 
       Some commands need additional inputs from the serial 
       port, so they need 2 or 3 state transitions (each one
       happening as soon as anything new is available from 
       the serial port) to be fully executed. After a command 
       is fully executed the state returns to its initial 
       value s=-1                                            */

    switch (s) {

      /* s=-1 means NOTHING RECEIVED YET ******************* */
      case -1:      

      /* calculate next state                                */
      if (val>47 && val<90) {
	  /* the first received value indicates the mode       
           49 is ascii for 1, ... 90 is ascii for Z          
           s=0 is change-pin mode;
           s=10 is DI;  s=20 is DO;  s=30 is AI;  s=40 is AO; 
           s=90 is query script type (1 basic, 2 motor);
           s=340 is change analog reference;
           s=400 example echo returning the input argument;
                                                             */
        s=10*(val-48);
      }
      
      /* the following statements are needed to handle 
         unexpected first values coming from the serial (if 
         the value is unrecognized then it defaults to s=-1) */
      if ((s>40 && s<90) || (s>90 && s!=340 && s!=400)) {
        s=-1;
      }

      /* the break statements gets out of the switch-case, so
      /* we go back and wait for new serial data             */
      break; /* s=-1 (initial state) taken care of           */


     
      /* s=0 or 1 means CHANGE PIN MODE                      */
      
      case 0:
      /* the second received value indicates the pin 
         from abs('c')=99, pin 2, to abs('¦')=166, pin 69    */
      if (val>98 && val<167) {
        pin=val-97;                /* calculate pin          */
        s=1; /* next we will need to get 0 or 1 from serial  */
      } 
      else {
        s=-1; /* if value is not a pin then return to -1     */
      }
      break; /* s=0 taken care of                            */


      case 1:
      /* the third received value indicates the value 0 or 1 */
      if (val>47 && val<50) {
        /* set pin mode                                      */
        if (val==48) {
          pinMode(pin,INPUT);
        }
        else {
          pinMode(pin,OUTPUT);
        }
      }
      s=-1;  /* we are done with CHANGE PIN so go to -1      */
      break; /* s=1 taken care of                            */
      


      /* s=10 means DIGITAL INPUT ************************** */
      
      case 10:
      /* the second received value indicates the pin 
         from abs('c')=99, pin 2, to abs('¦')=166, pin 69    */
      if (val>98 && val<167) {
        pin=val-97;                /* calculate pin          */
        dgv=digitalRead(pin);      /* perform Digital Input  */
        Serial.println(dgv);       /* send value via serial  */
      }
      s=-1;  /* we are done with DI so next state is -1      */
      break; /* s=10 taken care of                           */

      

      /* s=20 or 21 means DIGITAL OUTPUT ******************* */
      
      case 20:
      /* the second received value indicates the pin 
         from abs('c')=99, pin 2, to abs('¦')=166, pin 69    */
      if (val>98 && val<167) {
        pin=val-97;                /* calculate pin          */
        s=21; /* next we will need to get 0 or 1 from serial */
      } 
      else {
        s=-1; /* if value is not a pin then return to -1     */
      }
      break; /* s=20 taken care of                           */

      case 21:
      /* the third received value indicates the value 0 or 1 */
      if (val>47 && val<50) {
        dgv=val-48;                /* calculate value        */
	digitalWrite(pin,dgv);     /* perform Digital Output */
      }
      s=-1;  /* we are done with DO so next state is -1      */
      break; /* s=21 taken care of                           */


	
      /* s=30 means ANALOG INPUT *************************** */
      
      case 30:
      /* the second received value indicates the pin 
         from abs('a')=97, pin 0, to abs('p')=112, pin 15    */
      if (val>96 && val<113) {
        pin=val-97;                /* calculate pin          */
        agv=analogRead(pin);       /* perform Analog Input   */
	Serial.println(agv);       /* send value via serial  */
      }
      s=-1;  /* we are done with AI so next state is -1      */
      break; /* s=30 taken care of                           */



      /* s=40 or 41 means ANALOG OUTPUT ******************** */
      
      case 40:
      /* the second received value indicates the pin 
         from abs('c')=99, pin 2, to abs('¦')=166, pin 69    */
      if (val>98 && val<167) {
        pin=val-97;                /* calculate pin          */
        s=41; /* next we will need to get value from serial  */
      }
      else {
        s=-1; /* if value is not a pin then return to -1     */
      }
      break; /* s=40 taken care of                           */


      case 41:
      /* the third received value indicates the analog value */
      analogWrite(pin,val);        /* perform Analog Output  */
      s=-1;  /* we are done with AO so next state is -1      */
      break; /* s=41 taken care of                           */
      
      
      
      /* s=90 means Query Script Type: 
         (0 adio, 1 adioenc, 2 adiosrv, 3 motor)             */
      
      case 90:
      if (val==57) { 
        /* if string sent is 99  send script type via serial */
        Serial.println(0);
      }
      s=-1;  /* we are done with this so next state is -1    */
      break; /* s=90 taken care of                           */



      /* s=340 or 341 means ANALOG REFERENCE *************** */
      
      case 340:
      /* the second received value indicates the reference,
         which is encoded as is 0,1,2 for DEFAULT, INTERNAL  
         and EXTERNAL, respectively. Note that this function 
         is ignored for boards not featuring AVR or PIC32    */
         
#if defined(__AVR__) || defined(__PIC32MX__)

      switch (val) {
        
        case 48:
        analogReference(DEFAULT);
        break;        
        
        case 49:
        analogReference(INTERNAL);
        break;        
                
        case 50:
        analogReference(EXTERNAL);
        break;        
        
        default:                 /* unrecognized, no action  */
        break;
      } 

#endif

      s=-1;  /* we are done with this so next state is -1    */
      break; /* s=341 taken care of                          */



      /* s=400 roundtrip example function (returns the input)*/
      
      case 400:
      /* the second value (val) can really be anything here  */
      
      /* This is an auxiliary function that returns the ASCII 
         value of its first argument. It is provided as an 
         example for people that want to add their own code  */
         
      /* your own code goes here instead of the serial print */
      Serial.println(val);

      s=-1;  /* we are done with the aux function so -1      */
      break; /* s=400 taken care of                          */



      /* ******* UNRECOGNIZED STATE, go back to s=-1 ******* */
      
      default:
      /* we should never get here but if we do it means we 
         are in an unexpected state so whatever is the second 
         received value we get out of here and back to s=-1  */
      
      s=-1;  /* go back to the initial state, break unneeded */



    } /* end switch on state s                               */

  } /* end if serial available                               */
  
} /* end loop statement                                      */

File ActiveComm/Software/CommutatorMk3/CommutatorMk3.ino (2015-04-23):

//==============[Active Commutator ]==============//
//  by WALIII                                     //
//                                                //
//                                                //    
//                                                //
//=================={ENDOSCPOE}===================//
//------------------- V 1.0 ----------------------//

#include <Stepper.h>

// change this to the number of steps on your motor
#define STEPS 200
#define NOFIELD 505L 
#define TOMILLIGAUSS 1953
int speed2 = 300;
int numSteps = 1000;


Stepper mystepper(STEPS, 9, 8, 11, 10);
Stepper mystepper2(STEPS, 8, 11, 10, 8);

// the previous reading from the analog input
  int raw = 0;   // Range : 0..1024
  int compensated = 0;                 // adjust relative to no applied field 
  int gauss = 0;
 

void setup()
{
   Serial.begin(9600);
  // set the speed of the motor to 30 RPMs
  mystepper.setSpeed(speed2); // Fastest speed is 120 rpm
  mystepper2.setSpeed(speed2);
}

void DoMeasurement()
{
  
  float raw = analogRead(0);   // Range : 0..1024
  float compensated = raw - NOFIELD;                 // adjust relative to no applied field 
  float gauss = pow(compensated * TOMILLIGAUSS,2);
  Serial.print(gauss);
  Serial.print(" Gauss ");

  if (gauss > 30)  {   Serial.println("( to the RIGHT)");
    mystepper.step(-numSteps);
    mystepper2.step(0);}
    
  else if(gauss < -30) {  Serial.println("(to the LEFT)");
     mystepper.step(numSteps);
    mystepper2.step(0);}
    
  else               Serial.println();
}

void loop()
{
  delay(10);
  DoMeasurement();
  delay(50);
  
}

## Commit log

2014-12-25 Form validation added
    [DummyEndoscopeV1.stl, FinchScopeBaseplateMk1.0.stl, FinchScopeCapMk1.0.stl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]
2014-12-25 baseplate cover uploaded
    [BaseplateCoverV1.stl]
2014-12-25 reversed bad sides
    [FinchScopeMk4.4.stl, FinchScopeMk4.6.stl]
2014-12-26 test3
    test3
    [FinchScopeBaseplateMk1.0.stl]
2014-12-26 Reversed bad sides
    Reversed inner sides and magnet recesses.
    [FinchScopeCapMk1.0.stl]
2014-12-27 Fixed bad contours/edges
    [FinchScopeMk4.7.stl]
2014-12-29 Uploaded ActiveComm
    [ActiveCommMk1.1.stl]
2014-12-30 Updated file dimensions
    adjusted inner diameters for Kris commutator and HSR-1425CR continuous
    server
    [ActiveCommMk1.1.stl, ActiveCommMk1.2.stl]
2014-12-30 fixed bad geometries
    [ActiveCommMk1.2.stl, ActiveCommMk1.3.stl]
2014-12-30 removed bad faces
    [ActiveCommMk1.3.stl]
2015-01-06 increased GRIN lens hole diameter
    [FinchScopeMk4.8.stl]
2015-01-10 Updated Active comm
    Printed and verified working prototype.
    [ActiveCommGear1.stl, ActiveCommGear2.stl, ActiveCommLinker.stl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]
2015-01-10 organized files
    [BaseplateCoverV1.stl, DummyEndoscopeV1.stl, FinchScopeBaseplateMk1.0.stl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]
2015-01-25 squared off excitation path, shortened emession path
    [FinchScopeMk4.8.stl, FinchScopeMk5.0.stl]
2015-01-25 adjusted base plate mount
    [FinchScopeMk5.0.stl]
2015-01-27 added screw holes
    [ActiveCommLinkerMk1.1.stl]
2015-01-27 update schematic
2015-02-23 updated design
    [FinchScopeMk5.0.stl, FinchScopeMk5.3.stl]
2015-04-23 update new design
    [FinchScopeMk5.3.stl, FinchScopeMk5.4.stl]
2015-04-23 move active com files to separate directory
    [ActiveCommGear1.stl, ActiveCommGear2.stl, ActiveCommLinkerMk1.1.stl]
2015-05-03 update filename
    [ActiveCommGear1.stl, ActiveCommGear2.stl, ActiveCommLinkerMk1.1.stl]
2015-05-28 Update Readme for USB framegrabber
2015-06-02 added baseplate .stl. Tested and working
    [BaseplateMk1.1.stl]
2015-11-18 updated Flex cable designs
2015-11-22 add traces figure
2015-12-11 update assembly guide
2015-12-12 update links to schematics
2016-03-02 update most recent .stl files
    [BaseplateMk1.1.stl, BaseplateMk1.3.stl, FinchScopeBaseplateMk1.0.stl]
2016-03-16 update switch
2016-04-07 update camera docs
2016-10-09 update start frame conversion
2017-01-11 update filters
2017-01-12 update motif sorting and FS design files
    [FS_122016_2.0mm.skp, FS_122016_2.0mm.stl, FinchScopeMk5.4.stl]
2017-01-12 change catch case
2017-03-31 upload sample vid
2017-05-10 update image files for wireless
2017-05-10 update wireless header
2017-10-03 fix hall sensor confusion
2018-09-29 push CaBMI scope
    [CaBMI_BasePlate.skp, CaBMI_BasePlate.stl, CaBMI_BasePlate~.skp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]
2018-11-29 push new organizational scheme to branch
    [Bottem.skp, Bottem.stl, Bottem~.skp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]
2018-12-04 update naming conventions
    [FS_122016_2.0mm.skp, FS_122016_2.0mm.stl, Microscope Housing (FS_122016_2.0mm).skp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]
2019-02-11 Add editable commutator files
    [ActiveCommGear1.skp, ActiveCommGear2.skp, ActiveCommLinker.skp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]
2019-05-09 add files to my branch
    [CaBMI_BasePlate_which.stl, CaBMI_miniscope.skp, CaBMI_miniscope_18000um.stl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]
2019-07-17 update stl files
    [CaBMI_BasePlate_adjust_190523.skp, CaBMI_BasePlate_adjust_190523.stl, CaBMI_BasePlate_adjust_190523~.skp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]
2020-03-25 update tiff writer, readme and other things
    tiff writer can now write a single frame
    [CaBMI_miniscope_long_stem.skp, CaBMI_miniscope_long_stem.stl, CaBMI_miniscope_long_stem~.skp]
2020-08-19 ajust baseplate filenamse
    [CaBMI_BasePlate.skp, CaBMI_BasePlate.stl, CaBMI_BasePlate_adjust_190523.skp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]
2021-07-06 update readme for enclosure info
2021-07-12 upload sample video
